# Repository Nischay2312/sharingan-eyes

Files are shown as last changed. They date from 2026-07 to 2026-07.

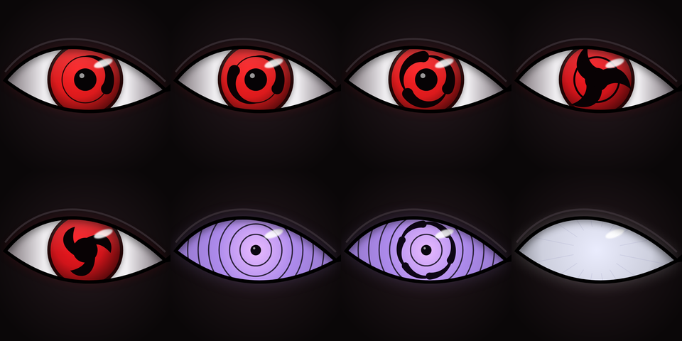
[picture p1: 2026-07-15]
tools/_test_montage.png

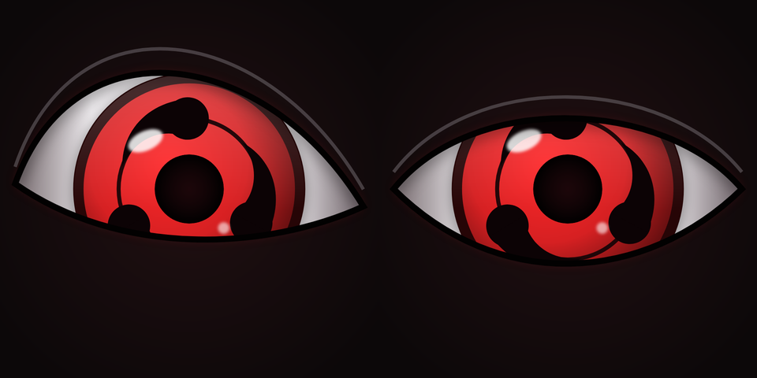
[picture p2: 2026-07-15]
tools/_test_shape.png

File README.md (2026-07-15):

# Sharingan — animated cosplay eye

A looping Sharingan/Rinnegan-style "eye" for an Obito (Naruto) cosplay mask: a
small round display behind a magnifying lens playing a board-agnostic animation.

This is a **standalone project**, separate from ScreenStreamWatch. It only
*reuses* the same Waveshare display bring-up by depending on the published BSP —
it does not copy or fork that firmware.

## Why it's structured this way

All animation logic renders into a fixed **240×240 RGB565** framebuffer that
knows nothing about the panel. The only board-specific code is two functions —
`eye_display_init()` and `eye_display_push_frame()`. So the same engine drives
both the board you have now and the round board arriving later; porting is a new
~120-line display backend, nothing else.

`sharingan/` is a single ESP-IDF project that builds ONE board at a time,
selected by `SHARINGAN_BOARD` (default: the AMOLED 2.06). Each board's firmware,
Kconfig defaults, and partition table live under `boards/<board>/`, so the two
firmwares stay separate — you just build from the repo root.

```
sharingan/
├── CMakeLists.txt                # THE project root; selects the board to build
├── components/
│   └── eye_core/                 # SHARED, board-agnostic engine (no BSP, no panel)
│       ├── eye_config.h          #   240×240 buffer geometry + RGB565 helper
│       ├── eye_params.[ch]       #   tunable params, scene table, NVS save/load
│       ├── eye_scene.[ch]        #   the realistic eye engine (8 dojutsu scenes)
│       ├── eye_info.[ch]         #   boot info screen (version, battery, uptime)
│       ├── eye_font.h            #   8x12 bitmap font (generated: tools/gen_font.py)
│       ├── eye_battery.h         #   battery contract (implemented per board)
│       ├── eye_imu.[ch]          #   QMI8658 accel + gyro flick gesture
│       ├── eye_console.[ch]      #   serial command REPL (live tuning)
│       ├── eye_demo.[ch]         #   render loop + screen list + gesture task
│       └── eye_display.h         #   the 2-function board contract
│
└── boards/                       # one folder per board => separate firmware
    ├── amoled_2_06/              # ESP32-S3-Touch-AMOLED-2.06 (default)
    │   ├── sdkconfig.defaults    #   octal PSRAM / 240MHz / LVGL
    │   ├── partitions.csv
    │   └── main/
    │       ├── app_main.c            # board setup, then eye_demo_run()
    │       ├── eye_display_amoled.c  # scales 240→410 (panel width) + centers
    │       ├── eye_battery_axp2101.c # AXP2101 PMIC fuel gauge (I2C)
    │       └── idf_component.yml     # waveshare AMOLED BSP + lvgl
    │
    └── lcd_1_28/                 # ESP32-S3-Touch-LCD-1.28 (round GC9A01)
        └── main/
            ├── app_main.c
            ├── eye_display_gc9a01.c  # raw esp_lcd, 1:1 push
            └── eye_battery_adc.c     # battery voltage via GPIO1 ADC (/3 divider)
```

## Screens — one flat cycle

The device boots on an **info screen**, and a **gyro flick** steps through one
flat list that wraps around; flicking the **opposite direction goes back**:

```
info  ->  clip 1 ... clip N (SD/flash playlist)  ->  8 dojutsu scenes  ->  info ...
```

The **info screen** shows firmware version, build date/time, IDF version, board
name, **battery level** (bar + percent + voltage + charging state), clip/scene
counts and uptime. Battery comes from the **AXP2101 PMIC** on the AMOLED (a
real fuel gauge) and from the **GPIO1 ADC** (÷3 divider, LiPo-curve estimate)
on the LCD 1.28.

## The dojutsu scenes (in-house animation engine)

`eye_scene.c` draws a **realistic anime eye**, not a flat pattern: an eyelid
silhouette on near-black skin, sclera with corner/lid shading, a big iris with
the dojutsu pattern, and a specular glint. It **animates like the reference
GIFs**: the eye *opens* when you arrive at a scene, *blinks* naturally at random
intervals, the gaze makes subtle saccades, the pattern spins slowly and
occasionally *flares* (fast spin burst + pupil constriction), and switching
scenes plays a **blink-morph** (close → pattern changes → reopen).

| # | Scene | Look |
|---|---|---|
| 0-2 | **tomoe1/2/3** | red Sharingan with 1/2/3 spinning tomoe |
| 3 | **mangekyou** | Obito/Kakashi pinwheel Mangekyou |
| 4 | **itachi** | Itachi's triple-blade Mangekyou |
| 5 | **rinnegan** | pale-violet ripple rings filling the whole eye |
| 6 | **tomoerin** | Rinnegan rings + 9 tomoe (Sasuke style) |
| 7 | **byakugan** | pale, pupil-less |

Every scene shares the same eye + behavior knobs (`set sspin/pupil/blink/gaze/
flare`, `color`), so you can recolor or retime any of them live.

## Switching screens — flick gesture

Give the board a quick **wrist flick** (a fast ~0→90°→back rotation, under
~500 ms) to go to the **next screen**; flick the **other way for the previous
screen**. The flick's rotation direction picks forward/backward. It latches, so
the new screen stays. This uses the QMI8658 **gyro** (a rate spike), sampled at
100 Hz in its own task.

The trigger defaults to **650 °/s** so only a deliberate flick fires it (casual
head/mask movement stays well under). Tune it live: **`set fhi <deg/s>` — higher
= less sensitive** (try 800–1000 if it still triggers too easily; 400 to make it
easier). `set flo` is the re-arm threshold; `flick off` disables it. If no IMU is
detected the demo still runs (use the console to switch).

## Serial console (live tuning)

Open the serial monitor (`idf.py -p COM4 monitor`, or the IDE's monitor), **click
into the terminal**, type a command and press **Enter** at the `eye>` prompt.
Input uses linenoise *dumb mode*, so it works even in monitors that don't echo —
you may not see characters as you type, but the command still runs. The boot log
prints which channel the console is on — on this board it should say
`serial console on USB-Serial-JTAG` (the USB-C port, not UART0). Commands:

| Command | Does |
|---|---|
| `help` | list all commands |
| `list` | list all screens (info / clips / scenes) + current |
| `screen <n>` | jump to screen n |
| `scene <id\|name>` | jump to a dojutsu (e.g. `scene rinnegan`); `effect` = alias |
| `next` / `prev` | step screens (same as the two flick directions) |
| `info` | jump to the info screen |
| `play` / `stop` | jump to the first clip / back to the scenes |
| `clip` | show clip playlist info |
| `get` | print every parameter |
| `set <key> <val>` | tune a parameter (see keys below) |
| `color <r> <g> <b>` | recolor the **current** scene (0–255 each) |
| `flick <on\|off>` | enable/disable the flick gesture |
| `reset` | restore all params to built-in defaults |
| `save` / `load` | persist / restore all params to NVS |

**`set` keys:** `speed` (global %), `scale` (eye size %), `sspin` (iris spin
ms/rev, sign = direction), `pupil` (radius px), `blink` (avg ms between blinks,
0 = off), `gaze` (saccade amplitude px, 0 = still), `flare` (avg ms between
spin flares, 0 = off), `fhi`, `flo`.

**Eye size:** `set scale <pct>` resizes the eye on the panel live. `100` = the
default fit (eye diameter = panel width, ~33 mm — the lens-calibration size).
Lower shrinks it; on the AMOLED, above 100 overscans toward the panel height
(circle fills more vertically, left/right edges clipped). Range 20–130.

Examples:
```
eye> scene tomoe3
eye> set sspin -2500      # spin the other way, 2.5 s/rev
eye> color 255 40 0       # orange sharingan
eye> set blink 8000       # blink less often
eye> set gaze 0           # eye stops looking around
eye> set speed 200        # everything 2x faster
eye> set scale 75         # shrink the eye to 75%
eye> set scale 120        # overscan bigger (AMOLED)
eye> save                 # remember it across reboots
```

## WiFi web control (both boards)

Optional web app with everything the console does and more (scene/clip
switching, upload/delete clips, flip H/V, brightness, colors, save/reboot).
WiFi is **off at boot** to save battery; a 10-minute idle timeout turns it back
off. Enable it from the **info screen's touch sliders** (both boards run the
same LVGL info screen now), or via the console: `wifi ap` (own hotspot — SSID
`SharinganEye-XXXX`, password
`uchihaXXXX`, both shown on screen) or `wifi sta` (joins your LAN; first time
opens a captive **setup portal** on `SharinganEye-Setup`). Then browse to
**http://sharingan-eye.local** (fallback `http://192.168.4.1` in AP mode).
`bright <5-100>` sets panel brightness (persisted). Code: `components/eye_web/`.

## Video / GIF clips

Real GIF/video clips are the middle section of the screen list: every clip in
the playlist is its own screen, so a **gyro flick** (or `next`/`prev`) walks
info → clips → scenes and wraps. Full design in [VIDEO_PLAN.md](VIDEO_PLAN.md).

### Generate a clip from scratch (recommended)

```sh
pip install -r tools/requirements.txt
python tools/eye_animator.py
```

**`eye_animator.py`** *creates* the dojutsu animation on the PC — no source GIF
needed — with far higher fidelity than the on-device procedural scenes: a
vector-rendered (skia) anime eye with sharp eyelids, glossy gradient iris,
crisp spinning pattern, specular glints and glow. All 8 dojutsu are available
(tomoe1/2/3, mangekyou, itachi, rinnegan, tomoerin, byakugan) with sliders for
eye shape (**anime ↔ round**), iris/pupil size, spin, blinks, gaze wander,
spin flare, colors. The timeline is **deterministic and seamless**: spin
completes whole revolutions per loop and blinks/gaze wrap cleanly, so the
exported clip loops forever without a visible jump. Preview is a fast proxy;
**Export GIF** / **Export .eyv** render at 4× supersampling in the background
(JPEG at 4:4:4 chroma so the red/black edges stay crisp).

### Convert an existing GIF/video

```sh
python tools/eye_studio.py yourclip.gif       # GUI (crop/trim/effects)
python tools/make_anim.py clip.gif -o a.eyv --fps 20 --quality 90   # or one-shot CLI
```

The **GUI** (`eye_studio.py`) does it all visually: scrub frames, drag a square
crop with the round-display circle drawn on, **trim** with In/Out markers, and a
tabbed **effects** panel (Photoshop-style) with live preview — brightness/
contrast/saturation/gamma/hue, **glow/bloom**, vignette, sharpen, per-channel
gains, color **tint**, invert, plus **animated** effects (hue-cycle, spin, pulse,
breathe) that move across the loop. Great for making a dull clip pop or recoloring
it. Then **Export .eyv**. (Effects live in `tools/eye_effects.py`.)

Clips are MJPEG (JPEG/frame) decoded on the fly; `set scale` still zooms them.
~18–30 fps depending on `--fps`.

### LCD 1.28″ — clips in flash (FATFS)

The `anim` partition is a **wear-levelled FATFS** volume (formatted
automatically on first boot), mounted at `/anim`. Manage clips over the **web
UI**: enable WiFi (`wifi ap` on the console), open `http://sharingan-eye.local`,
and upload/delete `.eyv` files on the Playback tab — exactly like the AMOLED's
SD card, no reflashing. (The old raw `flash_clip.ps1` / `.eyp` esptool flashing
is obsolete for this board.)

### AMOLED 2.06 — clips on SD card

No flashing for clips — the AMOLED reads them from the **SD card** folder
**`/eye/`**. Every `*.eyv` in that folder is a playlist entry (sorted by name).

1. Format an SD card FAT32, make a folder **`eye`**, copy your `.eyv` files into
   it (e.g. `eye/01_sharingan.eyv`, `eye/02_rinnegan.eyv`), insert the card.
2. Build/flash the AMOLED app once (`board.txt` = `amoled_2_06`, `idf.py flash`).
3. On boot it plays them; flick or `next` cycles. Swap clips later by just copying
   files onto the card — no reflash. (Folder set by `EYE_CLIP_DIR` in
   `boards/amoled_2_06/main/app_main.c`.)

## Lens calibration note (important)

On the AMOLED 2.06 the eye defaults to a diameter equal to the **panel width
(~410 px ≈ 33 mm)** and centered — not a raw 240 px. That makes the on-glass image
the same physical size as the 1.28″ round board's active area (Φ32.4 mm), so the
lens air-gap you calibrate now carries straight over. Use **`set scale <pct>`** to
resize the eye live (100 % = panel width); see the console section above.

---

## Build & flash (ESP-IDF / Espressif-IDE)

Tested toolchain: **ESP-IDF v5.5.x** (same as ScreenStreamWatch). Open/build the
repo root `G:\ElectronicsProj\sharingan` — it builds the AMOLED 2.06 by default.

### Espressif-IDE (Eclipse)
1. **File → Import → Espressif → Existing IDF Project**, point it at
   `G:\ElectronicsProj\sharingan` (the folder with `CMakeLists.txt`).
2. Set target **esp32s3** if asked.
3. Build (hammer), then **Flash** with the board's COM port selected.
4. Open the **Serial Monitor** to see logs (`sharingan`, `eye_demo`, `eye_imu`).

### Command line (ESP-IDF terminal)
```sh
cd G:\ElectronicsProj\sharingan
idf.py set-target esp32s3      # first time only
idf.py build
idf.py -p COM5 flash monitor   # use your board's port
```

### Switching boards (one file, no flags)

Both boards live in this one project. To switch which one builds, **edit
`board.txt`** (repo root) — change the single word to `amoled_2_06` or
`lcd_1_28` — and rebuild. CMake reconfigures automatically. The CMake log prints
`Sharingan board: <name>` so you can confirm. Each board keeps its own
`sdkconfig.<board>`, defaults, and partition table, so they never clobber.

```
# board.txt
amoled_2_06      # <- change to lcd_1_28 and rebuild to flash the round board
```

Switching in the same build directory triggers a near-full recompile (the two
boards use different components and PSRAM settings) — that's expected. If you'd
rather keep two warm builds, give each its own dir and the flag still works as a
one-off override:
```sh
idf.py -B build_amoled build flash                       # board.txt is ignored when -D is given
idf.py -B build_1_28 -DSHARINGAN_BOARD=lcd_1_28 build flash
```

First build pulls the Waveshare BSP + LVGL into `managed_components/`
(needs internet). `eye_core` is found automatically via `EXTRA_COMPONENT_DIRS`
in the project `CMakeLists.txt` — no registry publish needed.

Expected on boot (device shows the info screen; flick to move on):
```
I (...) eye_disp_amoled: ready: panel 410x502, eye 410px (scaled to width)
I (...) eye_bat: AXP2101 fuel gauge ready        # or ADC on the LCD 1.28
I (...) sharingan: AMOLED 2.06 eye demo starting
I (...) eye_scene: scene engine ready (8 scenes, 115200-byte polar LUTs)
I (...) eye_imu: QMI8658 found at 0x6B           # or "not detected" -> flick off
I (...) eye_console: serial console on USB-Serial-JTAG -- type 'help' and press Enter
I (...) eye_demo: running: 12 screens (info + 3 clips + 8 scenes), flick=on (QMI8658)
eye>
```

---

## Porting to the 1.28″ round board

Short version: write one new display backend and one I2C bus init; reuse
everything else. Full checklist in **[PORTING.md](PORTING.md)**.

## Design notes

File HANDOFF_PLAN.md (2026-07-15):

# Sharingan feature handoff plan

Handoff for continuing work after the Fable session ended mid-task (chat log from line 8785 in `claude_code_chat.md`). **Do not treat this as “greenfield”** — most firmware work is already landed in the tree; the next agent should verify, polish, and build the PC pre-renderer the user asked for at the very end.

---

## 1. What the user asked for

### A. Screen / mode system (firmware)

- Boot on an **info screen** (firmware version, compile date/time, board name, uptime, clip/scene counts).
- Show **battery capacity** using the correct hardware per board:
  - **AMOLED 2.06:** AXP2101 PMIC fuel gauge (I2C).
  - **LCD 1.28:** GPIO1 ADC with onboard ÷3 divider (LiPo curve estimate).
- Replace the old flat procedural effects with a **realistic anime eye** like the reference GIFs:
  - Eyelid silhouette on near-black skin.
  - Eye opening, blinking, morphing between patterns.
  - Sharingan spin, Rinnegan ripples, Mangekyō variants, Byakugan, etc.
- **One flat screen list** cycled by IMU flick:
  ```
  info → clip 1 … clip N (SD / flash playlist) → 8 in-house dojutsu scenes → info …
  ```
- **Bidirectional flick:** forward flick = next screen; opposite flick = previous screen.
- Old 4-effect engine (`eye_anim`) is obsolete; user cares about the **new** scenes, not the legacy effects.

### B. PC pre-rendered animations (follow-up, not started)

After the firmware work, the user asked for a **Python GUI** that:

- Generates the same style of eye animations **offline on the PC** (not real-time on ESP).
- Exports **GIF** (preview) and ideally **`.eyv`** (board playback) for higher visual fidelity.
- Is **customizable:** eye shape (more anime / less “normal round”), pattern design, spin, gaze wander, blink timing, colors.
- Leverages existing `.eyv` pipeline (`tools/make_anim.py`, `tools/eye_studio.py`) so clips are less taxing on the ESP than live procedural math.

**Priority:** realism and sell of the cosplay effect over having every possible dojutsu on day one.

---

## 2. Architecture (as implemented)

### Screen list (`eye_demo.c`)

| Index | Kind | Renderer |
|---|---|---|
| `0` | Info | `eye_info_render()` |
| `1 … N` | Video clip | `eye_video_next_frame()` (SD folder or flash partition) |
| `N+1 … N+8` | Dojutsu scene | `eye_scene_render()` |

- `eye_demo_set_screen(idx)` — wraps, runs enter hooks (clip select, `eye_scene_enter` vs `eye_scene_select`).
- `eye_demo_step_screen(±1)` — used by gesture task and console `next`/`prev`.
- Render task on **core 1**, always yields (watchdog-safe).

### Gesture (`eye_imu.c`)

- `eye_imu_poll_flick()` now returns **`+1` / `-1` / `0`** (signed peak gyro axis), not `bool`.
- Cooldown + re-arm thresholds unchanged (`fhi` / `flo` in params).

### Params (`eye_params` v3)

- `effect` → `scene` (`eye_scene_id_t`, 8 scenes).
- Per-scene colors; shared behavior knobs: `spin_ms`, `pupil_px`, `blink_ms`, `gaze_px`, `flare_ms`.
- NVS blob version bumped to **3** — first flash after upgrade resets saved tweaks.

### Battery contract (`eye_battery.h`)

| Board | File | Method |
|---|---|---|
| `amoled_2_06` | `boards/amoled_2_06/main/eye_battery_axp2101.c` | AXP2101 @ I2C 0x34 |
| `lcd_1_28` | `boards/lcd_1_28/main/eye_battery_adc.c` | ADC1_CH0 GPIO1, ÷3 divider |

### Scene engine (`eye_scene.c`)

- 240×240 RGB565, polar LUTs in PSRAM.
- Almond lid geometry (`EYE_HW`, `EYE_HU`, `EYE_HL`), blink state machine, gaze saccades, spin flares.
- 8 scenes: `tomoe1/2/3`, `mangekyou`, `itachi`, `rinnegan`, `tomoerin`, `byakugan`.
- `eye_scene_enter(id)` — dramatic open when arriving from info/clips.
- `eye_scene_select(id)` — blink-morph when scene → scene.

### Supporting pieces already in tree

| Artifact | Role |
|---|---|
| `tools/gen_font.py` → `eye_font.h` | 8×12 bitmap font for info screen |
| `eye_info.c` | Info screen layout (version, battery bar, counts, uptime) |
| `eye_console.c` | `list`, `screen`, `scene`, `info`, `play`, `stop`, updated `set` keys |
| `eye_video.c` | `eye_video_select()`, `eye_video_clip_name()` for playlist screens |
| `tools/eye_studio.py` | Existing GUI for cropping external GIF/video → `.eyv` |
| `tools/eye_effects.py` | Post-process effects (glow, tint, vignette) for clips |
| `VIDEO_PLAN.md` | Clip container format (`.eyv`); **still mentions `eye_anim` — update when touching docs** |

### Deleted / replaced

- `eye_anim.c` / `eye_anim.h` — removed from `eye_core/CMakeLists.txt`.
- Stale `build/` may still reference `eye_anim.c.obj` until a clean rebuild.

---

## 3. Current repo status

### Done (code present, matches Fable’s final design)

- [x] Screen list + boot-on-info
- [x] Directional flick forward/back
- [x] Info screen + font
- [x] Battery drivers (AXP2101 + ADC)
- [x] `eye_scene` engine (8 dojutsu)
- [x] Params v3 + console commands
- [x] `app_main` wiring (AMOLED: battery init, SD clip dir `/sdcard/eye`)
- [x] README / PORTING updated for new layout

### Not verified on hardware (next agent should do first)

- [ ] **Clean build + flash** both boards (`idf.py fullclean build flash`)
- [ ] Boot log: `eye_scene: scene engine ready`, `eye_demo: running: X screens (info + …)`
- [ ] Info screen: battery % / voltage / charging on AMOLED with battery attached
- [ ] Flick cycles info → clips → scenes → info; reverse flick goes back
- [ ] Visual QA behind lens: tomoe comma shapes, rinnegan ring spacing, **anime eye shape** vs reference images
- [ ] FPS / watchdog under full-width AMOLED upscale (render still on core 1)
- [ ] LCD 1.28 board build (pulls `esp_adc` per `boards/lcd_1_28/main/CMakeLists.txt`)

### Known gaps / polish

- **Eye shape:** C engine uses almond lids but user said it still looks too “normal” vs reference GIFs — expect iteration.
- **AXP2101 %:** Waveshare notes voltage-derived SOC can jump on plug/unplug; document in UI if needed.
- **PC harness:** Fable compiled `eye_scene.c` on PC in a temp scratchpad (PPM/GIF dumps). **Not committed to repo** — worth adding `tools/scene_harness/` for regression previews.
- **Python procedural animator:** **Not started** (session ended when user asked for GUI + handoff plan).

---

## 4. Recommended work order for the next agent

### Phase 0 — Verify firmware (1 session)

1. `idf.py fullclean build` from `sharingan/` (AMOLED default).
2. Flash, confirm USB-Serial-JTAG console (`help`, `list`, `scene tomoe3`).
3. Exercise full screen cycle + battery on info screen.
4. Log issues: watchdog, flick direction inverted, battery garbage, scene art.

Only fix blocking bugs in Phase 0; defer art tweaks to Phase 2 unless unusable.

### Phase 1 — PC scene harness (quick win)

Add `tools/scene_harness/`:

- Minimal C stubs (`esp_err.h`, `esp_log.h`, `esp_heap_caps.h`, `esp_timer.h`) + `main.c` that calls `eye_scene_render()` frame-by-frame.
- `build.sh` / `build.ps1` → dump PNG sequence or animated GIF.
- Lets art iteration **without** reflash (Fable already proved this workflow).

### Phase 2 — On-device visual polish

Tune in `eye_scene.c` (or harness first, then port numbers):

| Parameter | Location | User concern |
|---|---|---|
| Lid almond shape | `EYE_HW`, `EYE_HU`, `EYE_HL`, lid curve math | “More anime” silhouette |
| Tomoe commas | `tomoe_hit()`, `TOMOE_TAIL` | Reference image #12–14 |
| Rinnegan rings | `s_gap`, ripple drift | Hypnotic fill vs reference |
| Blink / open timing | `DUR_*` constants | Match reference GIF pacing |

### Phase 3 — Python procedural animator GUI (user’s new request)

**Goal:** `tools/eye_animator.py` — a desktop app that renders eye animations offline and exports GIF + `.eyv`.

**Decisions locked in with the user (2026-07-04):**

| Decision | Choice |
|---|---|
| Language | Python (integrates with existing `tools/` pipeline) |
| Rendering backend | **`skia-python`** — AA bézier paths, radial/sweep gradients, built-in blur for glow, path booleans for tomoe cutouts. Do **NOT** port `eye_scene.c` integer math; it reproduces the crunchy ESP look. |
| First scene / quality benchmark | **Mangekyō pinwheel** (matches user reference `G:\Chrome_Downloads\e342aa99d92cb8660fa1918986c595d0-ezgif.com-crop.gif`) |
| Timeline | **Fixed-length seamless loop** — spin completes integer revolutions; blinks/gaze placed so last frame flows into first. Loop length is a first-class GUI control. |
| On-device procedural scenes | Keep for now; may be hidden later if generated clips clearly win |
| GUI toolkit | Tkinter (consistency with `eye_studio.py`, zero new deps) |

#### 3.1 Design principles

- **Vector art, not pixel math** — build lids/iris/patterns as skia paths with gradients and blur. Only *parameter names* (spin, blink, gaze, flare) mirror the firmware so the mental model carries over.
- **Deterministic seamless loop** — no RNG at render time. The timeline is generated once from a seed + loop length; every event (blink, saccade, flare) has a start/duration placed so the loop wraps invisibly.
- **Lids are curves, not constants** — two cubic béziers meeting at pointed corners (upper peak biased nose-side), with an “anime ↔ round” interpolation slider. The C engine’s `EYE_HW/HU/HL` triple cannot make the reference silhouette.
- **Proxy preview / full-quality export** — GUI preview renders 240 px, no supersampling, cheap glow (fast enough for Tk). Export renders 4× (960 px), full blur, downsamples to 240, on a background thread with progress.
- **Export path reuses existing tools** (verified present in `make_anim.py`):
  - `frame_to_blob(im240, fmt, quality)` + `pack_eyv(out_path, blobs, fps, fmt, loop)`.
  - **Required tweak:** `encode_jpeg()` currently uses default 4:2:0 chroma subsampling, which smears saturated red/black edges (worst case for this art). Export at `quality≈95, subsampling=0` (4:4:4) and **verify `esp_new_jpeg` decodes 4:4:4 on-device early** — if it can’t, fall back to raw RGB565 for short clips or high-quality 4:2:0.
  - Optional post-pass via `eye_effects.py` (vignette etc.) on PIL frames.

#### 3.2 GUI layout (Tkinter, match `eye_studio.py` style)

```
┌─────────────────────────────────────────────────────────────┐
│ [Scene ▼]  [Preview]  [Timeline scrubber]  [Play loop]      │
├──────────────────┬──────────────────────────────────────────┤
│ Eye shape        │  Live 480×480 preview (2× of 240 proxy)  │
│  anime↔round     │                                          │
│  width, height   │                                          │
│  corner sharpness│                                          │
├──────────────────┤                                          │
│ Loop / behavior  │                                          │
│  loop length s   │                                          │
│  spin rev/loop   │                                          │
│  blinks per loop │                                          │
│  gaze amplitude  │                                          │
│  flare on/off    │                                          │
├──────────────────┤                                          │
│ Pattern / color  │                                          │
│  scene-specific  │                                          │
│  RGB sliders     │                                          │
├──────────────────┤                                          │
│ Export           │                                          │
│  fps, quality    │                                          │
│  [Export GIF]    │                                          │
│  [Export .eyv]   │                                          │
└──────────────────┴──────────────────────────────────────────┘
```

Note the behavior knobs are **per-loop** (spin revolutions per loop, blinks per
loop), not average intervals — that is what makes the loop seamless by
construction.

#### 3.3 Module split

```
tools/
  eye_animator.py      # Tk app entry
  eye_render/
    __init__.py
    geometry.py        # lid béziers, anime↔round interpolation, masks (skia paths)
    patterns.py        # tomoe, mangekyou, rinnegan, byakugan (skia paths + gradients)
    timeline.py        # seamless-loop event placement (blinks, saccades, flares)
    pipeline.py        # frame loop: skia surface → PIL → GIF / frame_to_blob/pack_eyv
  scene_harness/       # optional: keep C reference in sync
```

#### 3.4 Anime eye shape (explicit user ask)

Reference GIFs use a **taller, sharper almond** than a human eye:

- Increase vertical asymmetry (upper lid more curved, lower flatter).
- Corner points pulled horizontally (`EYE_HW` ratio > height).
- Optional “anime preset” slider: interpolates lid control points between round-human and sharp-anime.
- Sclera only in central region; lid fold grey band like reference image #11.

Validate by side-by-side overlay with user’s reference PNGs in the chat.

#### 3.5 Integration with firmware screen list

Two playback modes for generated content:

| Mode | How it appears on device |
|---|---|
| **A. Clip** | Export `.eyv` → SD `/eye/` or flash `anim` partition → screens `1…N` in list |
| **B. Live scene** | Keep procedural `eye_scene.c` for tuning via serial `set` |

User preference leans **A** for final cosplay quality; keep **B** for live tweaking. Document workflow in README:

```
python tools/eye_animator.py
# tune → Export .eyv → copy to SD card /eye/ → flick to clip screens
```

#### 3.6 Dependencies

Add to `tools/requirements.txt`:

```
pillow
numpy
skia-python        # vector renderer for eye_animator (pip installable, Windows wheels available)
```

#### 3.7 Milestones for Phase 3 — STATUS (2026-07-04)

1. [x] **Static Mangekyō frame** — skia render matches the reference look
   (sharp anime lids, glossy red iris, slim pinwheel blades, glint, glow).
2. [x] **Seamless loop** — 7 s / 175 frames; first-vs-last frame mean abs diff
   ≈ 1.3/255 (imperceptible); blink, saccades and flare all wrap cleanly.
3. [x] **`.eyv` export** — 4:4:4 JPEG q95 via local encoder + `pack_eyv`;
   header validated (EYEV v1, MJPEG, 240×240, 40 ms/frame, loop). ~15 KB/frame.
   **Still to do: decode-verify on the actual device** (SD `/eye/` on AMOLED).
4. [x] **GUI** — `tools/eye_animator.py`: scene picker, eye-shape sliders
   (anime↔round), loop controls, proxy preview + play, background 4× export
   with progress bar.
5. [x] **All 8 scenes** — tomoe1/2/3, mangekyou, itachi, rinnegan, tomoerin,
   byakugan render on the same pipeline (montage-verified).
6. [x] **Anime shape preset** — `EyeShape.anime` 0..1 slider interpolates
   round↔anime lid béziers.

**Remaining:** on-device playback test of an exported `.eyv` (JPEG 4:4:4
decode by `esp_new_jpeg`, red-edge quality, fps). If 4:4:4 fails to decode,
re-export with `subsampling=2` (4:2:0) at q97 or use `fmt="raw"` for short
clips.

---

## 5. Files to touch (checklist)

### Firmware verification only

- `components/eye_core/eye_demo.c`
- `components/eye_core/eye_scene.c`
- `boards/amoled_2_06/main/eye_battery_axp2101.c`
- `boards/lcd_1_28/main/eye_battery_adc.c`

### PC animator (new work)

- `tools/eye_animator.py` (new)
- `tools/eye_render/` (new package)
- `tools/requirements.txt`
- `tools/scene_harness/` (recommended)
- `README.md` — “Generating clips” section
- `VIDEO_PLAN.md` — replace `eye_anim_render` references with `eye_video_next_frame` / screen list

### Do not resurrect

- `eye_anim.c` / `eye_anim.h` — stay deleted.

---

## 6. Console quick reference (post-upgrade)

```
eye> list              # all screens; current marked
eye> info              # jump to boot info
eye> next / prev       # same as forward / backward flick
eye> scene rinnegan    # jump to scene
eye> play              # first clip (if any)
eye> get               # scene + spin/blink/gaze/flare
eye> set gaze 14
eye> set blink 5000
eye> color 255 0 0
eye> save
```

Expected boot (example):

```
I eye_bat: AXP2101 fuel gauge ready
I eye_scene: scene engine ready (8 scenes, …)
I eye_demo: running: 9 screens (info + 0 clips + 8 scenes), flick=on (QMI8658)
```

(Device boots on **info screen**, not a scene.)

---

## 7. Reference images

The user attached reference images in the chat (labeled #11–#14 in `claude_code_chat.md`):

- **#11** — eyelid silhouette, open/morph, sharingan spin (target motion language).
- **#12–#14** — sharingan / rinnegan / multi-type designs (target pattern art).

Use these for visual acceptance tests in harness GIFs before on-device flash.

---

## 8. Success criteria

### Firmware (Phase 0–2)

- [ ] No task watchdog under normal AMOLED use.
- [ ] Info screen shows plausible battery data on both boards.
- [ ] Full screen cycle works via flick both directions.
- [ ] At least **tomoe3** and **rinnegan** scenes read as “cosplay believable” behind the lens.

### PC animator (Phase 3)

- [ ] User can tune eye shape and export a looping GIF without editing code.
- [ ] Exported `.eyv` plays on device in the clip section of the screen list.
- [ ] Offline render looks **clearly better** than live `eye_scene.c` (glow, smoother lids, sharper tomoe).

---

*Generated from `claude_code_chat.md` (from user message at line 8785) and inspection of the `sharingan/` tree. No code changes in this step — plan only.*

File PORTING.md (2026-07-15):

# Porting to the ESP32-S3-Touch-LCD-1.28 (round, GC9A01)

The whole point of the architecture: **only the display backend and the I2C bus
setup change.** The 240×240 framebuffer, the animation, the IMU/QMI8658 driver,
the flick gesture, and the render loop are all shared in `components/eye_core/`
and move over untouched.

> **Status: this board is now wired up and buildable.** The GC9A01 backend, the
> `esp_lcd_gc9a01` dependency, the I2C bus, and the per-board sdkconfig are done.
> The one thing you MUST verify is the **SPI pin map** in
> `boards/lcd_1_28/main/eye_display_gc9a01.c` (see step 2) — if the screen stays
> black after flashing, that's almost certainly it.

## Board facts (from Waveshare docs)

| | AMOLED 2.06 (now) | LCD 1.28 (port) |
|---|---|---|
| Panel | 410×502, CO5300, **QSPI** | 240×240, GC9A01, **SPI** |
| Active area | ~33 mm wide | Φ32.4 mm round |
| Touch | FT3168 (I²C) | CST816S (I²C) |
| IMU | QMI8658 | **QMI8658 (same)** |
| SoC | ESP32-S3**R8**, 8 MB **octal** PSRAM, 32 MB flash | ESP32-S3**R2**, 2 MB **quad** PSRAM, 16 MB flash |

## What's already done

1. **1:1 push (no scaling).** `eye_display_gc9a01.c::eye_display_push_frame()`
   composes into a PSRAM ping-pong buffer (avoids tearing) and does a single
   `esp_lcd_panel_draw_bitmap()`. `scale < 100` shrinks + centers; the round panel
   can't overscan so `scale > 100` clamps to 1:1.
2. **GC9A01 driver dependency** added (`espressif/esp_lcd_gc9a01` in
   `boards/lcd_1_28/main/idf_component.yml`), backend enabled (no stub).
3. **IMU I²C bus** created on **SDA=GPIO6 / SCL=GPIO7** in `app_main.c`; the shared
   `eye_imu.c` probes the QMI8658 at 0x6B then 0x6A. Same flick gesture as AMOLED.
4. **sdkconfig** set for **quad** PSRAM / 16 MB flash, partition table wired.

## What YOU must verify on hardware

1. **SPI pin map** — top of `eye_display_gc9a01.c`. Confirmed from docs: `BL=2`,
   `SDA=6`, `SCL=7`. The SPI pins use Waveshare's standard 1.28″ demo mapping —
   **verify these against your schematic:**
   ```
   SCLK=10  MOSI=11  CS=9  DC=8  RST=14
   ```
   Black screen after flashing ⇒ fix these first (RST/DC/CS most likely).
2. **Color order / inversion** — the backend sets `invert_color(true)` and BGR
   element order (the usual GC9A01 combo). If colors look inverted, drop the
   invert; if red/blue are swapped, change `rgb_ele_order` to RGB.
3. **Orientation** — if the eye is mirrored/rotated on the glass, add
   `esp_lcd_panel_mirror()` / `esp_lcd_panel_swap_xy()` in the backend (never in
   the shared engine).
4. **Console** — left at the default UART0 (the board's USB-serial is on
   GPIO43/44 = UART0). If you can't type commands, switch it to USB-Serial-JTAG
   exactly like the AMOLED board: add `CONFIG_ESP_CONSOLE_USB_SERIAL_JTAG=y` to
   `boards/lcd_1_28/sdkconfig.defaults` and delete `sdkconfig.lcd_1_28`.

## What you do NOT touch

`eye_config.h`, `eye_scene.[ch]`, `eye_info.[ch]`, `eye_imu.[ch]`,
`eye_demo.[ch]`. If you find yourself editing any of these to make a board
work, that's a smell — the board-specific concern probably belongs in the
board's backend instead. A new board must provide THREE small files: the
display backend (`eye_display.h` contract), a battery reader (`eye_battery.h`
contract — PMIC, ADC, or a stub reporting `present=false`), and `app_main.c`.

## Build & flash the 1.28″ board

Build it in its **own build directory** so it never collides with the AMOLED
build (different deps, sdkconfig, and partition table):

```sh
cd G:\ElectronicsProj\sharingan
idf.py -B build_1_28 -DSHARINGAN_BOARD=lcd_1_28 set-target esp32s3
idf.py -B build_1_28 -DSHARINGAN_BOARD=lcd_1_28 build
idf.py -B build_1_28 -DSHARINGAN_BOARD=lcd_1_28 -p <COM> flash monitor
```

The AMOLED board keeps building the normal way (`idf.py build`, default `build/`),
so you can flip between the two without clobbering either.

First build pulls `esp_lcd_gc9a01` into `managed_components/` (needs internet).
Expect on boot: `eye_disp_gc9a01: GC9A01 ready (240x240, 1:1)`.

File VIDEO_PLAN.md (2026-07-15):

# Plan: GIF/Video playback on the eye

Goal: take any GIF/short video, convert it on the PC into a display-ready file,
flash it to the board, and have the firmware loop it on the eye. First target:
the **1.28″ round GC9A01** board. The design stays board-agnostic so the same
clip later plays on the AMOLED 2.06 with no re-conversion.

---

## 1. How it fits the current architecture

Nothing about the board interface changes. The engine already renders into a
fixed **240×240 RGB565** framebuffer and hands it to the board via
`eye_display_push_frame(fb240, scale_pct)`. A video is just a different source of
those 240×240 frames:

```
procedural effects ─┐
                    ├─> 240×240 RGB565 fb ─> eye_display_push_frame() ─> panel
video player ───────┘
```

So the video player decodes each frame into the same `fb` and reuses the exact
push path (byte-swap + BGR + scaling all already handled per board). On the round
board it's 1:1; on the AMOLED the same frames auto-scale to panel width.

---

## 2. Storage on the board

Frames live in their own **flash data partition** (`anim`), flashed independently
of the firmware so iterating on a clip doesn't require an app rebuild.

`boards/lcd_1_28/partitions.csv` (16 MB flash) gains:

```
# Name,   Type, SubType, Offset,  Size
nvs,      data, nvs,     0x9000,  0x6000,
phy_init, data, phy,     0xf000,  0x1000,
factory,  app,  factory, 0x10000, 4M,
anim,     data, spiffs,  ,        10M,
```

The firmware finds it by name and **memory-maps** it
(`esp_partition_mmap`) so JPEG frames are read straight from flash — **zero RAM
copy**, no filesystem layer.

Capacity (10 MB): at ~10–14 KB per JPEG frame that's ~750–1000 frames ≈
**35–50 s at 20 fps** — far more than a looping eye needs.

---

## 3. Clip container format (`.eyv`)

A single packed file, little-endian:

```
Header (32 bytes)
  0  magic        char[4]  "EYEV"
  4  version      u16      = 1
  6  format       u16      0 = MJPEG (JPEG per frame), 1 = raw RGB565_LE
  8  width        u16      240
 10  height       u16      240
 12  frame_count  u32
 16  frame_ms     u16      ms per frame (e.g. 50 = 20 fps)
 18  loop         u8       1 = loop forever, 0 = play once
 19  reserved     u8[13]
Frame index   frame_count × { offset u32, size u32 }   (offset from file start)
Frame data    concatenated JPEG (or raw RGB565) blobs
```

- **MJPEG** is the default (small, lets clips be long). JPEG decodes to
  `RGB565_LE` — the exact byte order the engine already uses.
- **raw RGB565** is supported for ultra-short clips where you want zero decode
  cost (112.5 KiB/frame, so only a handful fit).

---

## 4. PC conversion tool — `tools/make_anim.py`

```
python tools/make_anim.py input.gif -o anim.eyv \
       --fps 20 --quality 80 --fit cover --mask circle
```

Pipeline:
1. **Read frames** — GIF via Pillow (honors per-frame durations); video via
   `imageio`/`ffmpeg`. 
2. **Resample fps** to `--fps` (drop/duplicate frames to hit the target).
3. **Fit to square** — `--fit cover` (center-crop, default) or `contain`
   (letterbox), then resize to 240×240.
4. **Circular mask** (`--mask circle`, default for the round board) — paint
   outside the Φ circle black so it matches the bezel. `--mask none` to skip.
5. **(optional) color tweaks** — `--saturation`/`--gamma` to match the punchy
   look we tuned for the panel.
6. **Encode** each frame: JPEG at `--quality` (default 80) → or raw RGB565 with
   `--format raw`.
7. **Write `.eyv`** — header + index + data, print frame count / total size /
   estimated fps headroom.

Deps (PC only, documented in `tools/requirements.txt`): `pillow`, `imageio`,
`imageio-ffmpeg`, `numpy`.

---

## 5. Firmware changes

**New module `components/eye_core/eye_video.[ch]`** (board-agnostic):
- `eye_video_init()` — find `anim` partition, mmap it, validate header, keep the
  frame index.
- `eye_video_available()`, `eye_video_frame_count()`, `eye_video_frame_ms()`.
- `eye_video_decode(uint32_t idx, uint16_t *fb240)` — MJPEG: decode that frame's
  JPEG (from the mmap'd flash pointer) into `fb` via `esp_new_jpeg`; raw: memcpy.

**Dependency:** add `espressif/esp_new_jpeg` (same decoder the AMOLED streamer
used) to both boards' `idf_component.yml`; `eye_core` REQUIRES it + `esp_partition`.

**Integration in `eye_demo.c`:** add a playback mode. The render task does:
```
if (mode == VIDEO && eye_video_available())
    eye_video_decode(frame++, fb);   // wraps / stops per loop flag
else
    eye_anim_render(fb, t, &params);
push_frame(fb, params.scale_pct);
pace to frame_ms (video) or target fps (effects), always yielding
```

**Console commands** (extend `eye_console.c`):
- `play` — switch to video mode (if a clip is present).
- `stop` — back to procedural effects.
- `clip` — print the loaded clip's info (frames, fps, size).
- Optional `autoplay on|off` (persisted) — start in video mode on boot.

Flick gesture keeps cycling procedural effects; in video mode a flick can
`stop` back to effects (decided below).

---

## 6. Playback, timing, performance

- Decode 240×240 JPEG on the S3 ≈ 10–20 ms; SPI push ≈ 23 ms @ 40 MHz.
  → realistic **18–25 fps**. We can bump the GC9A01 SPI clock to **80 MHz**
  (Waveshare's demo uses it) to roughly halve the push and comfortably hit
  25–30 fps.
- Same always-yield pacing as the effect loop so the **task watchdog** stays fed.
- Double-buffering already exists in the board push, so decode(N+1) overlaps the
  SPI of frame N reasonably well.
- `scale_pct` still applies, so `set scale` shrinks/zooms the video too.

---

## 7. Developer workflow

```
# 1. Build a clip
python tools/make_anim.py sharingan.gif -o anim.eyv --fps 20

# 2. Flash just the clip to the anim partition (no app rebuild)
parttool.py --port COM4 --partition-name anim write_partition --input anim.eyv
#   (or: esptool.py --port COM4 write_flash <anim_offset> anim.eyv)

# 3. On the device console
eye> clip      # confirm it loaded
eye> play      # watch it loop
```

Firmware change (one-time): rebuild/flash the app once to add the player +
partition table.

---

## 8. Recommended defaults (please confirm / adjust)

| Decision | Recommended | Alternatives |
|---|---|---|
| Frame storage | MJPEG (JPEG/frame) | raw RGB565 (tiny clips only) |
| Location | raw `anim` partition + mmap | SPIFFS/LittleFS file |
| Trigger | console `play`/`stop`, effects by default on boot | auto-play clip on boot |
| Flick in video mode | flick → back to effects | flick ignored |
| Target fps | 20 (cap; bump SPI to 80 MHz) | 15 (safer) / 25–30 (needs 80 MHz) |
| Fit | cover (center-crop) + circle mask | contain (letterbox) |

---

## 9. Implementation milestones

1. **Format + tool** — write `make_anim.py`, define `.eyv`, produce a test clip;
   add a tiny PC-side verifier that previews frames.
2. **Partition + storage** — add `anim` partition, `eye_video_init()` mmap +
   header parse, log clip info on boot.
3. **Decode + play** — `eye_video_decode()` (MJPEG via esp_new_jpeg), wire the
   render task's video branch, `play`/`stop`/`clip` console commands.
4. **Tune** — bump SPI to 80 MHz, verify fps, circular mask alignment, colors.
5. **Polish** — `autoplay` pref, `--fit/--mask/--saturation` options, docs.

---

## 10. Future (out of scope for v1)

- AMOLED 2.06 playback (same `.eyv`, frames auto-scale; could ship a 410-native
  clip for max sharpness).
- Multiple clips / playlist, crossfade between clip and procedural effect.
- Audio on the AMOLED board (it has a speaker; the round board does not).
- On-the-fly streaming over USB/Wi-Fi instead of pre-flashing.
```

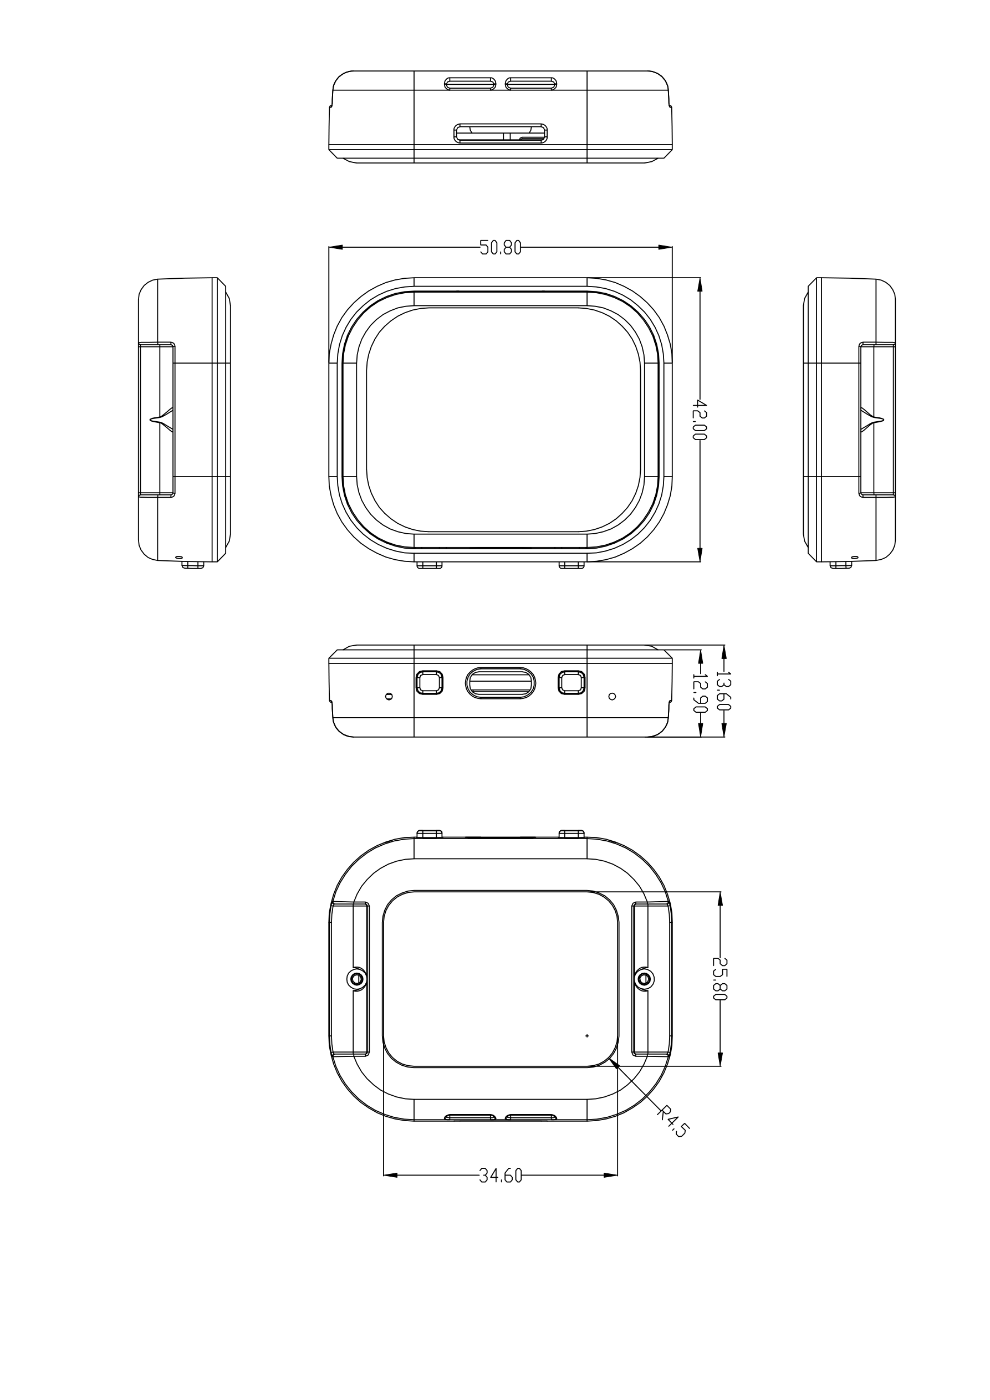
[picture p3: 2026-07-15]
hardware/watch_dims_page.png

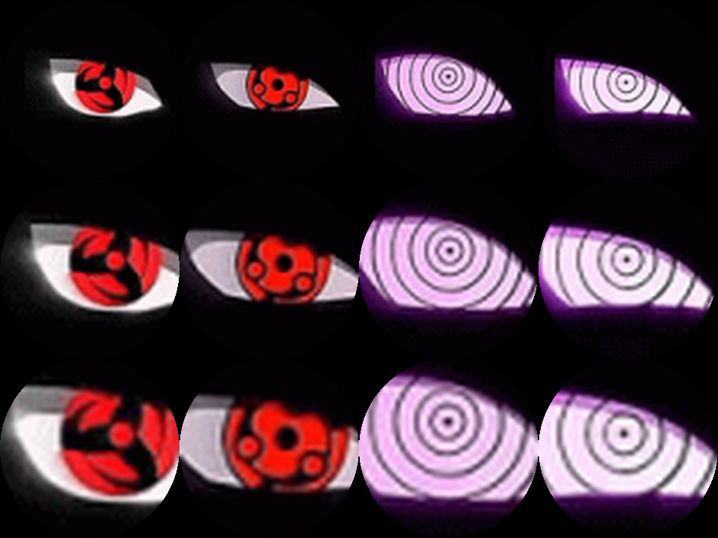
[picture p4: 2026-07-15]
preview_zoom.png

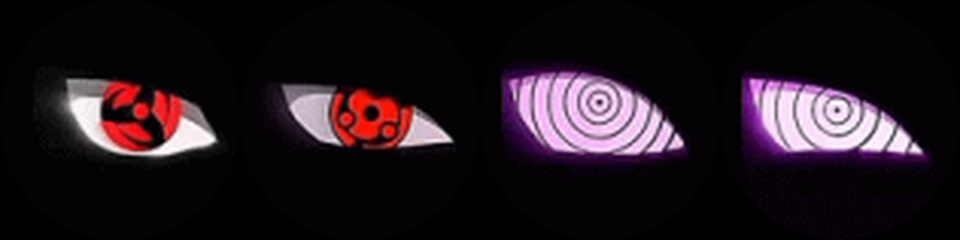
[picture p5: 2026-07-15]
preview_cover.png

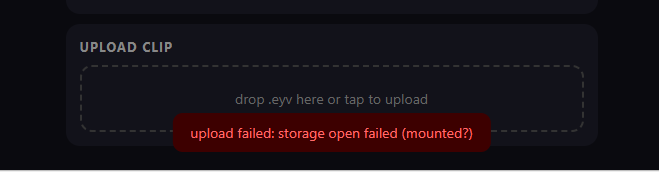
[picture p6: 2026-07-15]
uplod_failed.png

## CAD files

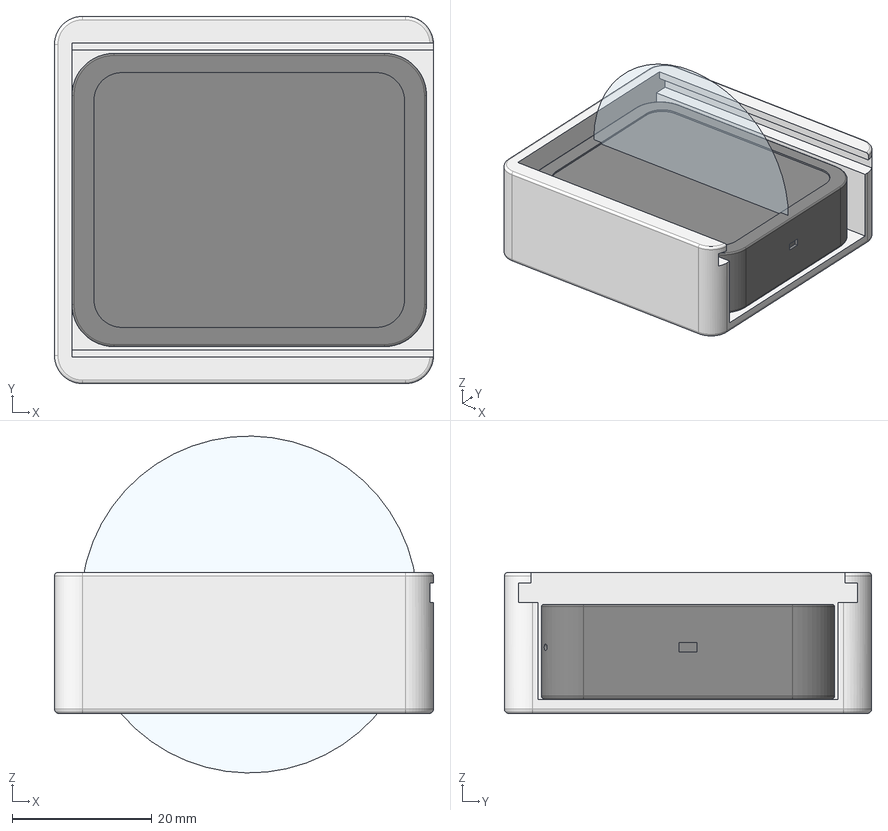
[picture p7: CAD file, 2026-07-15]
hardware/eye_assembly.step
54.3 x 52.6 x 48.3 mm
case
watch
lens

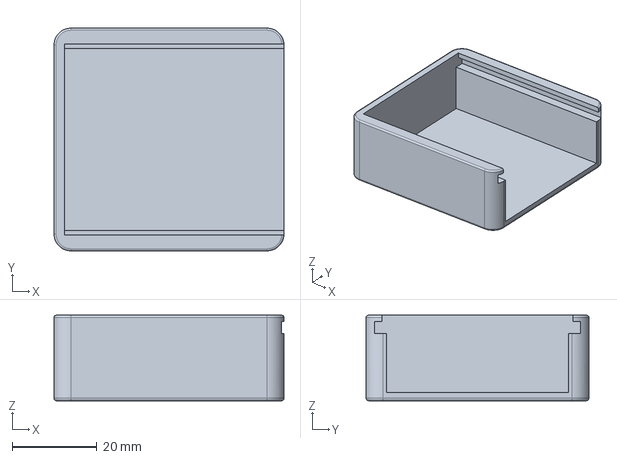
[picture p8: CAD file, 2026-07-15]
hardware/eye_case.step
54.3 x 52.6 x 20.2 mm

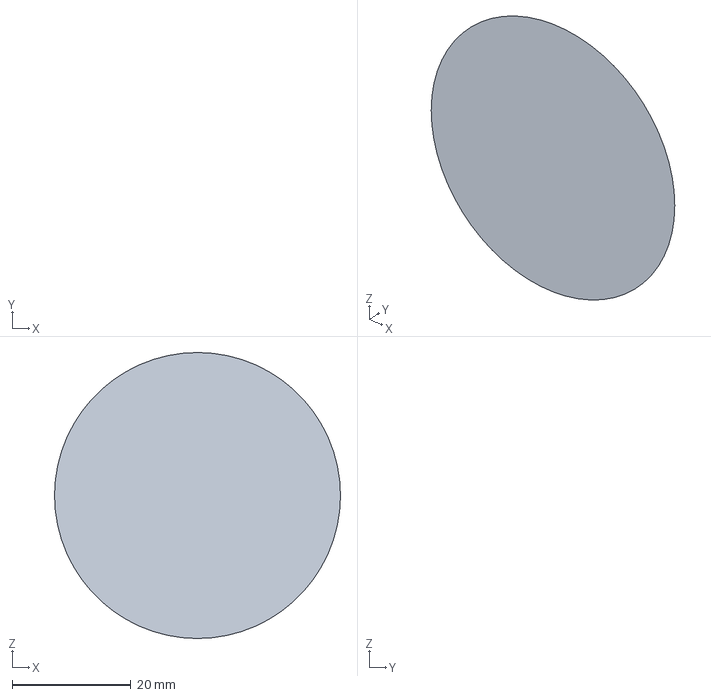
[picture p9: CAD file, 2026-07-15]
hardware/lens_48x14_plano_convex.step
48.3 x 0 x 48.3 mm

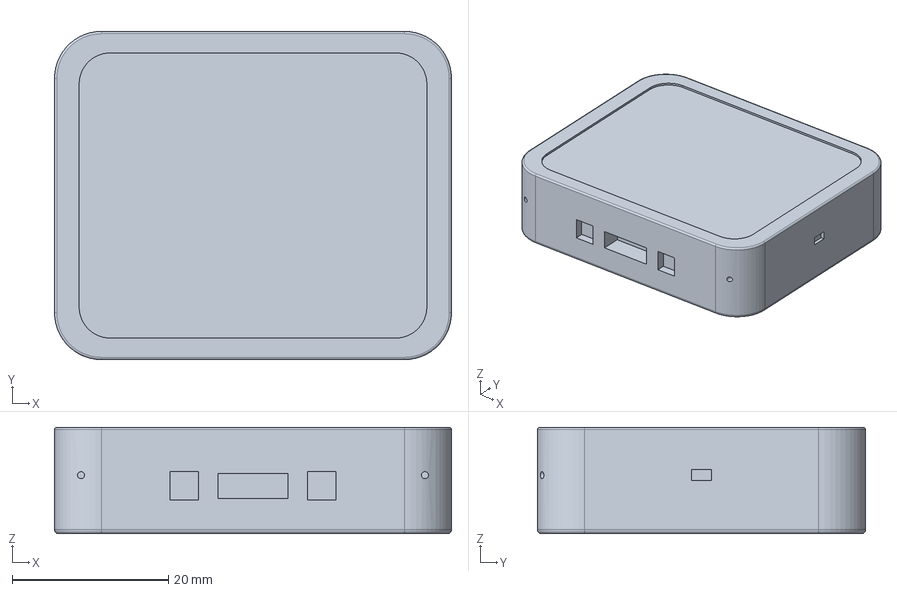
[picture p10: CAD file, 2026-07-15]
hardware/watch_amoled_2_06.step
50.8 x 42.0 x 13.6 mm

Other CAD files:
hardware/eye_case.stl
hardware/lens_48x14_plano_convex.stl
hardware/watch_amoled_2_06.stl

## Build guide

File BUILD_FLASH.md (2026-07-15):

# Sharingan Eye — Build & Flash Reference

## Project layout

One IDF project, two boards. The active board is set in `board.txt` (one word,
no other changes needed). Each board keeps its own `sdkconfig.<board>` and a
dedicated build directory so switching boards never contaminates the other.

```
board.txt          ← change this to switch target (amoled_2_06 | lcd_1_28)
boards/
  amoled_2_06/     ← Waveshare AMOLED 2.06  (COM4 in current setup)
    partitions.csv
    sdkconfig.defaults
    main/
  lcd_1_28/        ← Waveshare LCD 1.28     (COM5 in current setup)
    partitions.csv
    sdkconfig.defaults
    main/
build_amoled/      ← AMOLED build artifacts (gitignored)
build_1_28/        ← LCD 1.28 build artifacts (gitignored)
```

---

## One-time IDF environment setup (PowerShell)

Run this once per PowerShell session before any `idf.py` commands:

```powershell
$env:IDF_PYTHON_ENV_PATH = "$HOME\.espressif\python_env\idf5.5_py3.11_env"
. "$HOME\esp\v5.5.1\esp-idf\export.ps1" *> $null
Set-Location "G:\ElectronicsProj\sharingan"
```

---

## Build

### AMOLED 2.06

```powershell
# Switch board (if not already set)
(Get-Content board.txt) -replace '^lcd_1_28', '#lcd_1_28' |
  ForEach-Object { $_ -replace '^#?amoled_2_06', 'amoled_2_06' } |
  Set-Content board.txt

idf.py -B build_amoled build
```

### LCD 1.28

```powershell
# Switch board (if not already set)
(Get-Content board.txt) -replace '^amoled_2_06', '#amoled_2_06' |
  ForEach-Object { $_ -replace '^#?lcd_1_28', 'lcd_1_28' } |
  Set-Content board.txt

idf.py -B build_1_28 build
```

Both commands: CMake re-runs automatically when `board.txt` changes; only
changed source files recompile.

---

## Flash (first time / partition table change)

The first flash after a partition table change must write bootloader +
partition table + otadata + app together. `idf.py flash` does this:

### AMOLED on COM4

```powershell
idf.py -B build_amoled -p COM4 flash
```

Writes (in order):
| Address | File |
|---|---|
| `0x0` | `build_amoled/bootloader/bootloader.bin` |
| `0x8000` | `build_amoled/partition_table/partition-table.bin` |
| `0x10000`  | `build_amoled/ota_data_initial.bin` |
| `0x20000`  | `build_amoled/sharingan_eye.bin` |

### LCD 1.28 on COM5

```powershell
idf.py -B build_1_28 -p COM5 flash
```

Writes (in order):
| Address | File |
|---|---|
| `0x0` | `build_1_28/bootloader/bootloader.bin` |
| `0x8000` | `build_1_28/partition_table/partition-table.bin` |
| `0x10000`  | `build_1_28/ota_data_initial.bin` |
| `0x20000`  | `build_1_28/sharingan_eye.bin` |

> **COM port busy?** Close the VS Code serial monitor (the plug icon in the
> ESP-IDF toolbar) or any other terminal holding the port before flashing.

---

## Flash (OTA — after first flash)

Once the board is running OTA-capable firmware you can update it wirelessly:

1. Build the new firmware: `idf.py -B build_amoled build`
2. Open the board's web UI (connect to `SharinganEye-XXXX` AP or via home
   WiFi at `http://sharingan-eye.local`)
3. Go to **System → Firmware update (OTA)**
4. Select `build_amoled/sharingan_eye.bin`
5. The board flashes and reboots automatically

> **Note:** The `.bin` file must be built for the correct board. Do not flash
> an AMOLED binary onto the LCD board or vice versa.

---

## Monitor (serial log)

```powershell
# AMOLED
idf.py -B build_amoled -p COM4 monitor

# LCD
idf.py -B build_1_28  -p COM5 monitor

# Exit monitor: Ctrl+]
```

## Build + flash + monitor in one go

```powershell
idf.py -B build_amoled -p COM4 flash monitor
idf.py -B build_1_28  -p COM5 flash monitor
```

---

## Full erase (factory reset NVS / WiFi credentials)

```powershell
idf.py -B build_amoled -p COM4 erase-flash
idf.py -B build_1_28  -p COM5 erase-flash
# Then reflash normally afterwards
```

---

## VS Code (ESP-IDF extension)

The extension reads `board.txt` via CMake on every build, so the workflow is:

1. Edit `board.txt` to the target board name
2. **ESP-IDF: Build** (Ctrl+E B)
3. Select the COM port in the status bar
4. **ESP-IDF: Flash** (Ctrl+E F)

The extension uses `build/` (not `build_amoled/` or `build_1_28/`) as its
output directory, so CLI and VS Code builds are in separate trees — they don't
interfere.

---

## Partition tables

Both boards use OTA-capable layouts (2 × 2MB app slots):

### AMOLED 2.06 (`boards/amoled_2_06/partitions.csv`)

| Name | Type | SubType | Offset | Size |
|---|---|---|---|---|
| nvs | data | nvs | 0x9000 | 24K  |
| phy_init | data | phy | 0xf000 | 4K |
| otadata  | data | ota | 0x10000  | 8K |
| ota_0 | app  | ota_0 | 0x20000  | 2M |
| ota_1 | app  | ota_1 | 0x220000 | 2M |

### LCD 1.28 (`boards/lcd_1_28/partitions.csv`)

| Name | Type | SubType | Offset | Size |
|---|---|---|---|---|
| nvs | data | nvs | 0x9000 | 24K  |
| phy_init | data | phy | 0xf000 | 4K |
| otadata  | data | ota | 0x10000  | 8K |
| ota_0 | app  | ota_0 | 0x20000  | 2M |
| ota_1 | app  | ota_1 | 0x220000 | 2M |
| anim | data | fat | 0x420000 | 10M  |

Current firmware size: ~1.47MB (28% free in 2MB slot).

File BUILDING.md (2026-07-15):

# Building the Sharingan firmware

How firmware images are generated for the two boards in this repo. This is the
practical, copy-pasteable reference; the short version also lives in
[README.md](README.md) under "Build & flash".

One ESP-IDF project builds **one board at a time**. The board is a single
setting (`board.txt`); everything board-specific (display backend, battery
driver, Kconfig defaults, partition table, generated `sdkconfig.<board>`) is
keyed off it, so the two boards never clobber each other.

- `amoled_2_06` - Waveshare ESP32-S3-Touch-AMOLED-2.06 (410x502, CO5300 QSPI, LVGL)
- `lcd_1_28` - Waveshare ESP32-S3-Touch-LCD-1.28 (240x240, GC9A01 SPI, raw esp_lcd)

---

## 1. Toolchain

- **ESP-IDF v5.5.1**, installed at `C:\Users\nisch\esp\v5.5.1\esp-idf`.
- Target: **esp32s3** (both boards). Pinned in the top
  [CMakeLists.txt](CMakeLists.txt) so a fresh configure never defaults to plain
  `esp32`.
- Tools (compiler, ninja, python venv) under `C:\Users\nisch\.espressif`.

### Environment activation (important gotcha)

The stock `export.ps1` derives the Python venv name from whatever `python` is
first on `PATH`. On this machine that resolves to Python 3.13, but IDF actually
installed its venv as **`idf5.5_py3.11_env`**, so a plain
`. export.ps1` fails with *"virtual environment ... py3.13_env not found"*.

Activate by pointing `IDF_PYTHON_ENV_PATH` at the real venv first:

```powershell
$env:IDF_PYTHON_ENV_PATH = "$HOME\.espressif\python_env\idf5.5_py3.11_env"
. "$HOME\esp\v5.5.1\esp-idf\export.ps1"
```

After this, `idf.py` is on `PATH` for the rest of the shell session. The
Espressif-IDE (Eclipse) and the VS Code ESP-IDF extension handle this
automatically; the note above is only for a raw PowerShell terminal.

---

## 2. Pick the board

Selection precedence (first that is set wins), from the top
[CMakeLists.txt](CMakeLists.txt):

1. `-DSHARINGAN_BOARD=<name>` on the `idf.py` line (one-off override)
2. `$env:SHARINGAN_BOARD` (environment variable)
3. [board.txt](board.txt) - the easy way; first non-comment line
4. fallback: `amoled_2_06`

The easy way is to edit [board.txt](board.txt) to the single word `amoled_2_06`
or `lcd_1_28`. CMake reconfigures automatically on the next build and prints:

```
-- Sharingan board: amoled_2_06  (edit board.txt to switch)
```

Always confirm that line matches the board you intend to flash.

---

## 3. Build, flash, monitor

```powershell
cd G:\ElectronicsProj\sharingan
idf.py set-target esp32s3      # first time in a fresh build dir only
idf.py build
idf.py -p COM5 flash monitor   # use your board's COM port
```

- First build pulls the Waveshare BSP + LVGL into `managed_components/` (needs
  internet). `eye_core` is found via `EXTRA_COMPONENT_DIRS`, no registry publish.
- Output image: `build/sharingan_eye.bin`. The build footer prints the app-
  partition usage.
- Serial console (commands + logs) is on **USB-Serial-JTAG** (the USB-C port) on
  the AMOLED, UART on the LCD.

---

## 4. Where the config comes from (and a gotcha)

Each board gets its own generated config file and defaults:

- `sdkconfig.<board>` - the **active, generated** config the build reads
  (e.g. `sdkconfig.amoled_2_06`). Set by `SDKCONFIG` in the top CMakeLists.
- `boards/<board>/sdkconfig.defaults` - the seed values (PSRAM mode, 240 MHz,
  LVGL options, console channel, partition-table path, enabled fonts, ...).

**Gotcha:** `sdkconfig.defaults` is only applied when `sdkconfig.<board>` does
**not already** contain that key (i.e. on first configure). Editing a default
that already has a materialised value in `sdkconfig.<board>` will *not* take
effect on a normal rebuild. When you change `sdkconfig.defaults`, either:

- edit the same key directly in `sdkconfig.<board>` (fast, targeted), or
- `idf.py reconfigure` after deleting the stale value, or
- delete `sdkconfig.<board>` (or the whole `build/`) and rebuild to reseed.

(This is exactly why enabling `CONFIG_LV_FONT_MONTSERRAT_28` needed the value
set in `sdkconfig.amoled_2_06`, not just in the defaults.)

Partition tables also differ per board: `boards/<board>/partitions.csv`,
selected via the defaults.

---

## 5. Switching boards

Editing [board.txt](board.txt) and rebuilding in the same `build/` dir triggers
a near-full recompile (different components + PSRAM settings) - expected. To keep
two warm builds, give each its own build dir; the `-D` flag overrides
`board.txt` as a one-off:

```powershell
idf.py -B build_amoled build flash                    # AMOLED (uses board.txt only if no -D)
idf.py -B build_1_28 -DSHARINGAN_BOARD=lcd_1_28 build flash
```

---

## 6. Clips (not part of the app image)

- **AMOLED**: clips are read from the SD card folder `/sdcard/eye` at runtime -
  no reflash. Copy `*.eyv` files onto the card (build them with
  `tools/eye_animator.py` or `tools/make_anim.py`).
- **LCD 1.28**: clips live in the flash `anim` data partition (FATFS); see
  [README.md](README.md) for the image/upload flow.

---

## 7. Quick troubleshooting

- **`idf.py` not recognised** - environment not activated; see section 1.
- **`virtual environment ... py3.13_env not found`** - set `IDF_PYTHON_ENV_PATH`
  to the `idf5.5_py3.11_env` venv before sourcing `export.ps1`.
- **A `sdkconfig.defaults` change didn't take** - see the gotcha in section 4.
- **Wrong board flashed** - check the `-- Sharingan board: <name>` CMake line and
  `board.txt`.
- **Font / symbol `undeclared` at compile** - the matching `CONFIG_LV_FONT_*`
  isn't set in the active `sdkconfig.<board>`.

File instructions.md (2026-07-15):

CONTEXT
I'm building an animated "eye" for an Obito (Naruto) cosplay mask: a small round
display behind a magnifying lens, playing a looping Sharingan/Rinnegan-style
animation. I have one board now and a second arriving in 2 days. I want code that
runs on the board I have today but is structured to port to the other with minimal
changes.

BOARD I HAVE NOW (build target for this task)
- Waveshare ESP32-S3-Touch-AMOLED-2.06
- 2.06" AMOLED, 410x502, CO5300 driver, QSPI interface
- FT3168 capacitive touch (I2C), QMI8658 6-axis IMU
- ESP32-S3R8, 8MB PSRAM, 32MB flash
- Wiki: https://www.waveshare.com/wiki/ESP32-S3-Touch-AMOLED-2.06

BOARD ARRIVING IN 2 DAYS (port target: architect for it, do not build for it yet)
- Waveshare ESP32-S3-Touch-LCD-1.28
- 1.28" round LCD, 240x240, GC9A01 driver, SPI interface, ~33.4mm active diameter
- CST816 touch (I2C), QMI8658 6-axis IMU
- ESP32-S3R2, 2MB PSRAM, 16MB flash
- Docs: https://docs.waveshare.com/ESP32-S3-Touch-LCD-1.28

ENVIRONMENT
- ESP-IDF via Espressif-IDE on Windows.
- Existing project at G:\ElectronicsProj\ScreenStreamWatch, already set up for the
  AMOLED 2.06 board. Read its README, docs, and components first. REUSE its existing
  display bring-up. Do NOT hand-roll the CO5300 QSPI init.
- Read the local project docs AND both wiki URLs above before writing any code.

TASK
1. Read the project and both boards' docs to understand the display pipeline that's
   already in place (LVGL vs raw esp_lcd, pin config, panel init).
2. Add a self-contained "animated eye" demo that runs on the AMOLED 2.06 now.
3. Animation: a looping circular eye. A placeholder is fine (e.g. concentric rings
   with a rotating tomoe/ripple). I'll swap in real Sharingan/Rinnegan frames later,
   so make the animation source easy to replace.

ARCHITECTURE REQUIREMENTS (important, for portability)
- Render everything into a fixed 240x240 RGB565 framebuffer. All animation and logic
  draws into this buffer and must be board-agnostic.
- Put ALL board-specific code behind a thin interface: display_init() and
  push_frame(uint16_t* buf240x240). On the AMOLED, push_frame centers/blits the
  240x240 buffer into the 410x502 panel. (The 1.28 board's push_frame will later be a
  1:1 push; I'll add that when it arrives.)
- If the project uses LVGL, render the buffer via an LVGL canvas; if it talks to
  esp_lcd directly, push the raw buffer. Pick based on what you find.
- Keep the QMI8658 IMU read in a board-agnostic helper (same chip on both boards).
  Stub in a simple tilt trigger that switches between two animations.

LENS-TEST REQUIREMENT
- The future round board's active area is 33.4mm. The AMOLED 2.06 is ~33mm wide.
  Draw the eye inside a circle whose diameter equals the full panel WIDTH (~410px),
  centered, so the physical image size matches the future board. This lets me
  calibrate the lens air-gap now and have it carry over.

DELIVERABLES
- The new source files and how they plug into the existing project.
- Build and flash instructions for ESP-IDF / Espressif-IDE.
- A short note listing exactly what I'll change to port to the 1.28 round GC9A01
  board later.

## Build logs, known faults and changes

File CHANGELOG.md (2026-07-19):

# Changelog

All notable changes to the Sharingan eye firmware are recorded here.

## v1.1

### Fixed
- **AMOLED silent freeze.** The AMOLED (SH8601) display would freeze on a
  random frame with no crash or watchdog. Root cause (found by bisection): the
  eye was drawn as an LVGL image, and the LVGL task's QSPI panel flush
  intermittently lost its trans-done interrupt and wedged in `wait_for_flushing`
  while holding the port mutex, so the next frame's display lock blocked forever.
  It was unrelated to WiFi, brightness, console, IMU, or the JPEG decoder.
- **Per-clip settings no longer collide.** Overrides were keyed on the first 15
  chars of the filename; clips sharing a 15-char prefix overwrote each other.
  Keys are now a short readable prefix plus an FNV-1a hash of the full name.
  (Note: existing saved overrides are orphaned by the key change and must be
  re-saved once.)

### Changed
- **AMOLED display bypasses LVGL entirely.** The backend now gets the raw
  panel/IO handles from `bsp_display_new`, owns its own color-trans-done
  semaphore, and pushes frames straight to the panel. A lost/late trans-done
  just times out and the next frame re-arms — it can no longer deadlock.
- **Pipelined rendering.** A flush task on core 0 transfers each composed frame
  in parallel with the render/decode task on core 1 (double-buffered with
  backpressure), holding the smooth 20 fps the LVGL path had.
- Frames are composed into a full-panel canvas and transferred band-by-band
  through an internal DMA bounce buffer; only the margins around the eye are
  cleared each frame (not the whole panel).
- **AMOLED info screen renders as raster** (via `eye_info_render`) instead of
  the old LVGL widget screen, since LVGL is no longer in the AMOLED build.
- **Brightness is bus-safe.** Web/console brightness (SH8601 command 0x51) is
  serialized with the flush task's pixel DMA via a bus mutex, so it can't
  collide on the shared QSPI bus.

### Added
- Storage/SD size bar in the web UI (Info tab card + Clips tab header).

## v1.0

Initial release: dual-board ESP32-S3 firmware for wearable animated eye
displays.

- Boards: Waveshare LCD 1.28 (GC9A01, 240×240) and AMOLED 2.06 (SH8601).
- WiFi web UI for clip upload/delete/play, OTA firmware updates, and eye sync
  across multiple boards.
- PSRAM-optimised RAM layout; Python desktop clip manager (`tools/eye_manager.py`).

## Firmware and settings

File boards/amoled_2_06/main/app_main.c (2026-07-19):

/*
 * Firmware entry point for the Waveshare ESP32-S3-Touch-AMOLED-2.06.
 *
 * Board "personality": board-specific setup (panel + I2C via the BSP), then
 * hands control to the shared, board-agnostic eye engine (eye_demo_run).
 *
 * POST FREEZE-FIX ARCHITECTURE
 * ----------------------------
 * The AMOLED silent-freeze was the LVGL panel-flush wedge. The display backend
 * now draws straight to the SH8601 (no LVGL) via a pipelined flush task, so the
 * whole feature set is restored on that foundation:
 *   clips + scene effects + gesture flick (IMU) + serial console + battery +
 *   RASTER info screen + WiFi/web control.
 * The info screen is passed as NULL hooks on purpose -> eye_demo_run renders it
 * with eye_info_render (raster), NOT the old LVGL widget screen (LVGL is gone).
 *
 * Brightness note: web/console brightness goes through eye_display_set_brightness
 * (not bsp_display_brightness_set directly) so the SH8601 0x51 command is
 * serialized with the flush task's pixel DMA on the shared QSPI bus.
 */

#include "esp_log.h"
#include "esp_vfs_fat.h"
#include "nvs_flash.h"

#include "bsp/esp-bsp.h"

#include "eye_display.h"   /* eye_display_init / push_frame / set_brightness */
#include "eye_demo.h"      /* eye_demo_run                              */
#include "eye_video.h"     /* eye_video_set_dir                        */
#include "eye_battery.h"   /* AXP2101 fuel gauge (eye_battery_axp2101.c) */
#include "eye_info.h"      /* eye_info_set_board                        */
#include "eye_net.h"       /* WiFi + web control lifecycle (eye_web)    */
#include "eye_console.h"   /* eye_console_set_extra (wifi/bright cmds)  */
#include "eye_webserver.h" /* eye_webserver_log_init (early log capture) */

/* Bus-safe brightness, defined in eye_display_amoled.c (serializes the SH8601
 * 0x51 command with the flush task on the shared QSPI bus). */
void eye_display_set_brightness(int pct);

static const char *TAG = "sharingan";

#define EYE_CLIP_DIR    BSP_SD_MOUNT_POINT "/eye"

static void board_brightness_set(int pct)
{
    eye_display_set_brightness(pct);
}

static void board_storage_info(uint64_t *total_kb, uint64_t *free_kb)
{
    uint64_t total = 0, free = 0;
    esp_vfs_fat_info(BSP_SD_MOUNT_POINT, &total, &free);
    *total_kb = total / 1024;
    *free_kb  = free  / 1024;
}

void app_main(void)
{
    /* Capture boot logs into the web console ring buffer as early as possible. */
    eye_webserver_log_init();

    /* Some IDF components expect an initialized NVS; do it defensively. */
    esp_err_t nvs = nvs_flash_init();
    if (nvs == ESP_ERR_NVS_NO_FREE_PAGES || nvs == ESP_ERR_NVS_NEW_VERSION_FOUND) {
        ESP_ERROR_CHECK(nvs_flash_erase());
        ESP_ERROR_CHECK(nvs_flash_init());
    }

    ESP_ERROR_CHECK(eye_display_init());

    /* QMI8658 (gesture) shares the board I2C bus. bsp_i2c_init() is idempotent
     * if the BSP display bring-up already initialized it. */
    (void)bsp_i2c_init();
    i2c_master_bus_handle_t imu_bus = bsp_i2c_get_handle();

    /* AXP2101 PMIC (battery gauge for the info screen) is on the same bus. */
    eye_battery_init(imu_bus);
    eye_info_set_board("AMOLED 2.06 410x502");

    if (bsp_sdcard_mount() == ESP_OK) {
        eye_video_set_dir(EYE_CLIP_DIR);
        ESP_LOGI(TAG, "SD mounted; clip folder %s", EYE_CLIP_DIR);
    } else {
        ESP_LOGW(TAG, "SD mount failed; video disabled (effects only)");
    }

    const eye_net_config_t net_cfg = {
        .clip_dir         = EYE_CLIP_DIR,
        .brightness_set   = board_brightness_set,
        .get_storage_info = board_storage_info,
    };
    eye_net_init(&net_cfg);
    eye_console_set_extra(eye_net_register_console);

    ESP_LOGI(TAG, "AMOLED 2.06 eye engine starting (full: web + raster info)");

    /* NULL UI hooks -> raster info screen (no LVGL). Never returns. */
    eye_demo_run(eye_display_push_frame, imu_bus, NULL);
}

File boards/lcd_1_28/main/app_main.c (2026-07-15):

/*
 * Firmware entry point for the Waveshare ESP32-S3-Touch-LCD-1.28 (round).
 *
 * Structure mirrors the AMOLED board: board-specific setup, then the same
 * shared eye_demo_run(). Differences vs. the AMOLED:
 *   - eye_display_gc9a01.c instead of eye_display_amoled.c (1:1 push, PWM BL)
 *   - clips live on a FATFS-formatted 'anim' FLASH partition (/anim) instead
 *     of an SD card -- same web upload/list/delete, different storage
 *   - no LVGL: the raster info screen shows the WiFi status lines, and the
 *     `wifi`/`bright` console commands stand in for the touch sliders
 */

#include "esp_log.h"
#include "esp_vfs_fat.h"
#include "nvs_flash.h"
#include "driver/i2c_master.h"
#include "wear_levelling.h"

#include "eye_display.h"
#include "eye_demo.h"
#include "eye_video.h"     /* eye_video_set_dir                        */
#include "eye_battery.h"   /* battery ADC on GPIO1 (eye_battery_adc.c) */
#include "eye_info.h"      /* eye_info_set_board / net provider        */
#include "eye_console.h"   /* eye_console_set_extra                    */
#include "eye_net.h"       /* WiFi + web control lifecycle (eye_web)   */
#include "eye_ui.h"        /* native LVGL info screen (eye_ui_lvgl)    */
#include "eye_webserver.h" /* eye_webserver_log_init (early log capture) */

static const char *TAG = "sharingan_128";

/* The 'anim' flash partition, FATFS-mounted: the clip playlist scans it and
 * the web UI uploads/deletes files in it (like the AMOLED's SD folder). */
#define EYE_CLIP_DIR  "/anim"

/* Provided by eye_display_gc9a01.c (LEDC backlight; CST816S -> LVGL input). */
void      eye_display_set_brightness(int pct);
esp_err_t eye_display_add_touch(i2c_master_bus_handle_t bus);

static void board_storage_info(uint64_t *total_kb, uint64_t *free_kb)
{
    uint64_t total = 0, free = 0;
    esp_vfs_fat_info(EYE_CLIP_DIR, &total, &free);
    *total_kb = total / 1024;
    *free_kb  = free  / 1024;
}

/* Native info-screen hooks -- this board runs LVGL now too (eye_ui_lvgl). */
static const eye_ui_hooks_t s_ui = {
    .available = eye_ui_available,
    .show      = eye_ui_info_show,
    .update    = eye_ui_info_update,
};

/* Shared I2C bus for the QMI8658 (confirmed from Waveshare docs: SDA=6, SCL=7;
 * the CST816 touch sits on the same bus but the eye demo doesn't use touch). */
#define IMU_I2C_PORT  I2C_NUM_0
#define IMU_PIN_SDA   6
#define IMU_PIN_SCL   7

static i2c_master_bus_handle_t imu_bus_init(void)
{
    i2c_master_bus_config_t cfg = {
        .i2c_port = IMU_I2C_PORT,
        .sda_io_num = IMU_PIN_SDA,
        .scl_io_num = IMU_PIN_SCL,
        .clk_source = I2C_CLK_SRC_DEFAULT,
        .glitch_ignore_cnt = 7,
        .flags.enable_internal_pullup = true,
    };
    i2c_master_bus_handle_t bus = NULL;
    if (i2c_new_master_bus(&cfg, &bus) != ESP_OK) {
        ESP_LOGW(TAG, "I2C bus init failed; tilt disabled");
        return NULL;
    }
    return bus;
}

/* Mount (formatting on first use) the wear-levelled FATFS clip partition. */
static void anim_fs_mount(void)
{
    static wl_handle_t s_wl = WL_INVALID_HANDLE;
    const esp_vfs_fat_mount_config_t cfg = {
        .max_files              = 4,
        .format_if_mount_failed = true,     /* first boot: raw -> FATFS */
        .allocation_unit_size   = 4096,
    };
    esp_err_t err = esp_vfs_fat_spiflash_mount_rw_wl(EYE_CLIP_DIR, "anim",
                                                     &cfg, &s_wl);
    if (err == ESP_OK) {
        eye_video_set_dir(EYE_CLIP_DIR);
        ESP_LOGI(TAG, "anim FATFS mounted at %s (upload clips via the web UI)",
                 EYE_CLIP_DIR);
    } else {
        ESP_LOGW(TAG, "anim FATFS mount failed (%s); video disabled",
                 esp_err_to_name(err));
    }
}

void app_main(void)
{
    eye_webserver_log_init();

    esp_err_t nvs = nvs_flash_init();
    if (nvs == ESP_ERR_NVS_NO_FREE_PAGES || nvs == ESP_ERR_NVS_NEW_VERSION_FOUND) {
        ESP_ERROR_CHECK(nvs_flash_erase());
        ESP_ERROR_CHECK(nvs_flash_init());
    }

    ESP_ERROR_CHECK(eye_display_init());
    i2c_master_bus_handle_t imu_bus = imu_bus_init();
    eye_display_add_touch(imu_bus);   /* CST816S shares the IMU I2C bus */

    /* No PMIC on this board: battery % is estimated from the GPIO1 ADC. */
    eye_battery_init(NULL);
    eye_info_set_board("LCD 1.28 round 240");

    anim_fs_mount();

    /* WiFi + web control (same app as the AMOLED): the LVGL info screen has
     * the WiFi/brightness controls, and the console (`wifi ap|sta|off`,
     * `bright <pct>`) works as well. */
    const eye_net_config_t net_cfg = {
        .clip_dir           = EYE_CLIP_DIR,
        .brightness_set     = eye_display_set_brightness,
        .get_storage_info   = board_storage_info,
    };
    eye_net_init(&net_cfg);
    eye_console_set_extra(eye_net_register_console);
    eye_info_set_net_provider(eye_net_info_lines);   /* raster fallback only */

    ESP_LOGI(TAG, "1.28\" round eye demo starting");
    eye_demo_run(eye_display_push_frame, imu_bus, &s_ui); /* never returns */
}

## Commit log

2026-07-15 Initial release: dual-board Sharingan eye firmware v1.0
    ESP32-S3 firmware for wearable animated eye displays on two boards:
    - Waveshare LCD 1.28 (GC9A01 240x240)
    - Waveshare AMOLED 2.06 (SH8601)
    Features: WiFi web UI for clip upload/delete/play, OTA firmware, eye
    sync across multiple boards, PSRAM-optimised RAM layout, Python desktop
    clip manager tool (tools/eye_manager.py).
    [eye_assembly.step, eye_case.step, eye_case.stl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]
2026-07-15 Fix tangled per-clip settings from colliding NVS keys
    Per-clip overrides were keyed on the first 15 characters of the clip
    filename (the NVS key length limit). Any two clips sharing a 15-char
    prefix mapped to the same key, so saving settings on one silently
    overwrote the other -- e.g. obito_skin_eye_sharinga_right_side.eyv and
    obito_skin_eye_rinnegan_right_side_side.eyv both keyed 'obito_skin_eye_'.
    Key is now up to 6 readable characters plus an 8-hex FNV-1a hash of the
    full name, so distinct clips never share a slot.
    Note: the key scheme change orphans previously saved overrides; clips
    need their settings saved once more.
2026-07-19 Fix AMOLED silent freeze: draw direct to panel instead of via LVGL
    The AMOLED display would freeze on a random frame with no crash or
    watchdog. Root cause (found by bisection): the eye went through an LVGL
    image, and the LVGL task's SH8601 QSPI flush intermittently lost its
    trans-done interrupt and wedged in wait_for_flushing while holding the
    port mutex -- so the next frame's display lock blocked forever. It had
    nothing to do with WiFi, brightness, console, IMU, or the JPEG decoder.
    Rewrite the AMOLED backend to bypass LVGL entirely: get the raw panel/IO
    handles from bsp_display_new, own the color-trans-done semaphore, and
    push each frame straight to the panel. A lost/late trans-done now j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
    [app_main.c, eye_display_amoled.c]
